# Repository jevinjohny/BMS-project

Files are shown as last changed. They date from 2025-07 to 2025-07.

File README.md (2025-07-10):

# 🔋 Battery Management System for Low Voltage Low Power Domestic Equipment

🎓 **B.Tech Final Year Project**  
🏫 Government Engineering College, Barton Hill  
👤 **Author**: Jevin Johny V  

---

## 📘 Overview

This project presents a compact, stackable **Battery Management System (BMS)** designed for small domestic devices like robotic vacuum cleaners. It incorporates passive cell balancing, safety protections, and real-time SoC estimation.

---

## 🛠️ Tools & Technologies

- **Microcontroller**: Texas Instruments TMS320F28379D  
- **PCB Design**: KiCad (schematic + 2-layer layout + Gerber)  
- **Simulation**: MATLAB Simulink Embedded Coder  
- **Programming**: Embedded C, ADC configuration, interrupt handling  
- **IC Used**: BQ77915 (cell balancing, protection)

---

## 🧑‍💻 My Contributions

- ✅ Complete microcontroller development (ADC, ISR, SoC logic)
- ✅ Designed custom 2-layer PCB using KiCad with Gerber generation
- ✅ Simulated SoC estimation algorithm in MATLAB
- ✅ Tested protection features and built prototype on hardware

---

## 📂 Project Structure

| Folder | Description |
|---|---|
| `kicad` | Schematic, layout, and Gerber files for the PCB |
| `screenshots` | Photos of hardware, layout, schematic, and testing |
| `README.md` | Project summary |
| `LICENSE` | MIT License (recommended for open source use) |

---

## 🖼️ Preview
### 🔌 Schematic
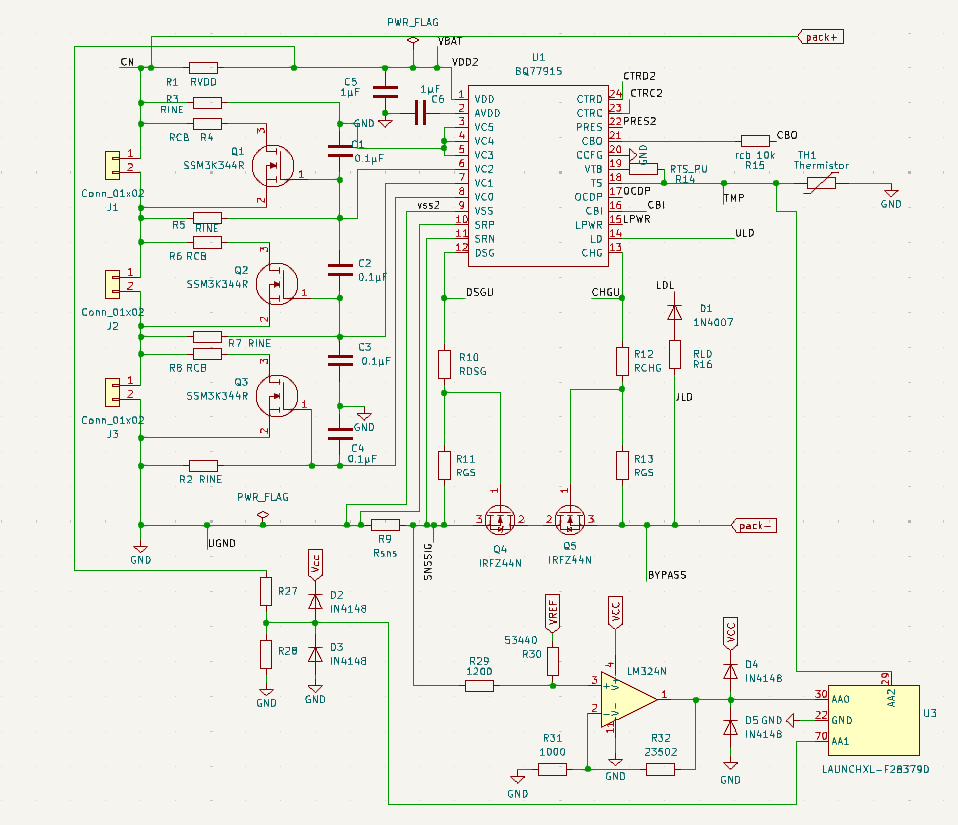
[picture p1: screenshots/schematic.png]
Schematic


### 🔌 PCB Design
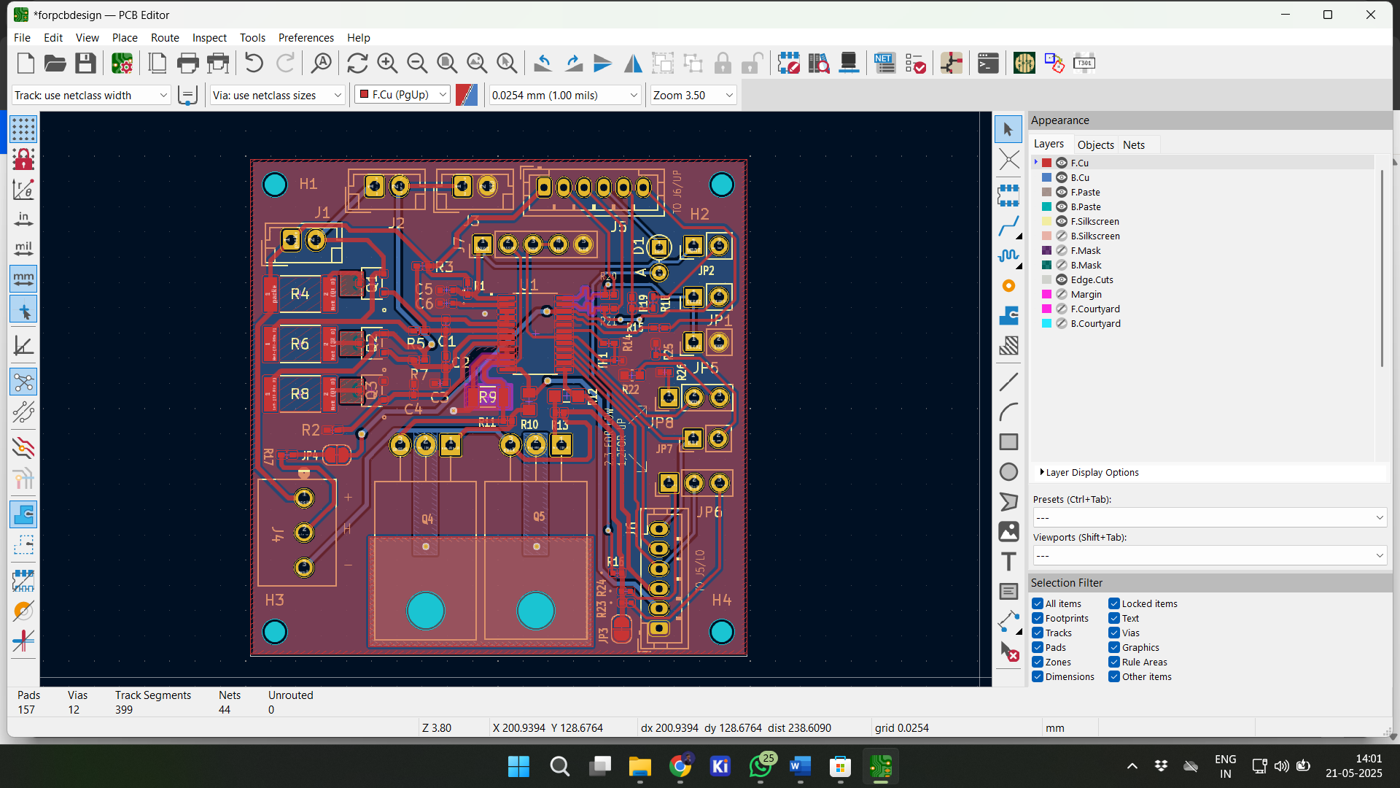
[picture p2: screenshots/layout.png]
Layout


### 🧪 Testing
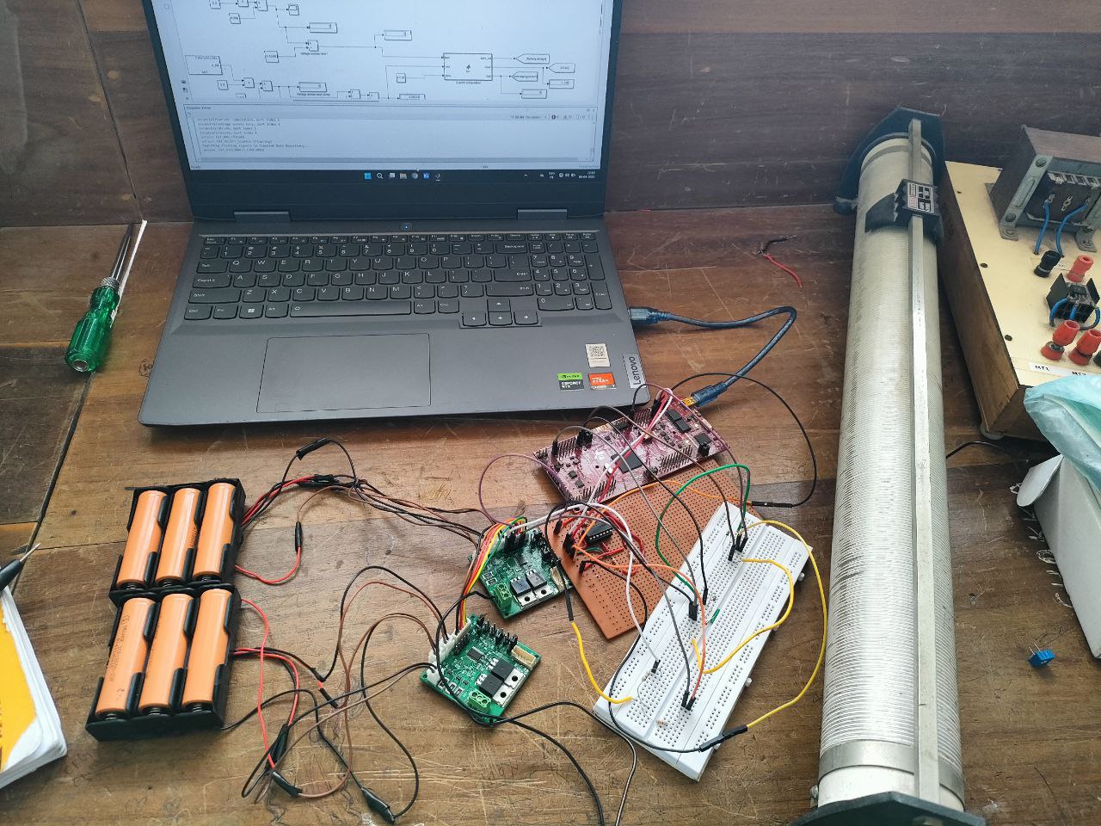
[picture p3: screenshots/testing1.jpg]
Testing


### 📊 MATLAB Simulation
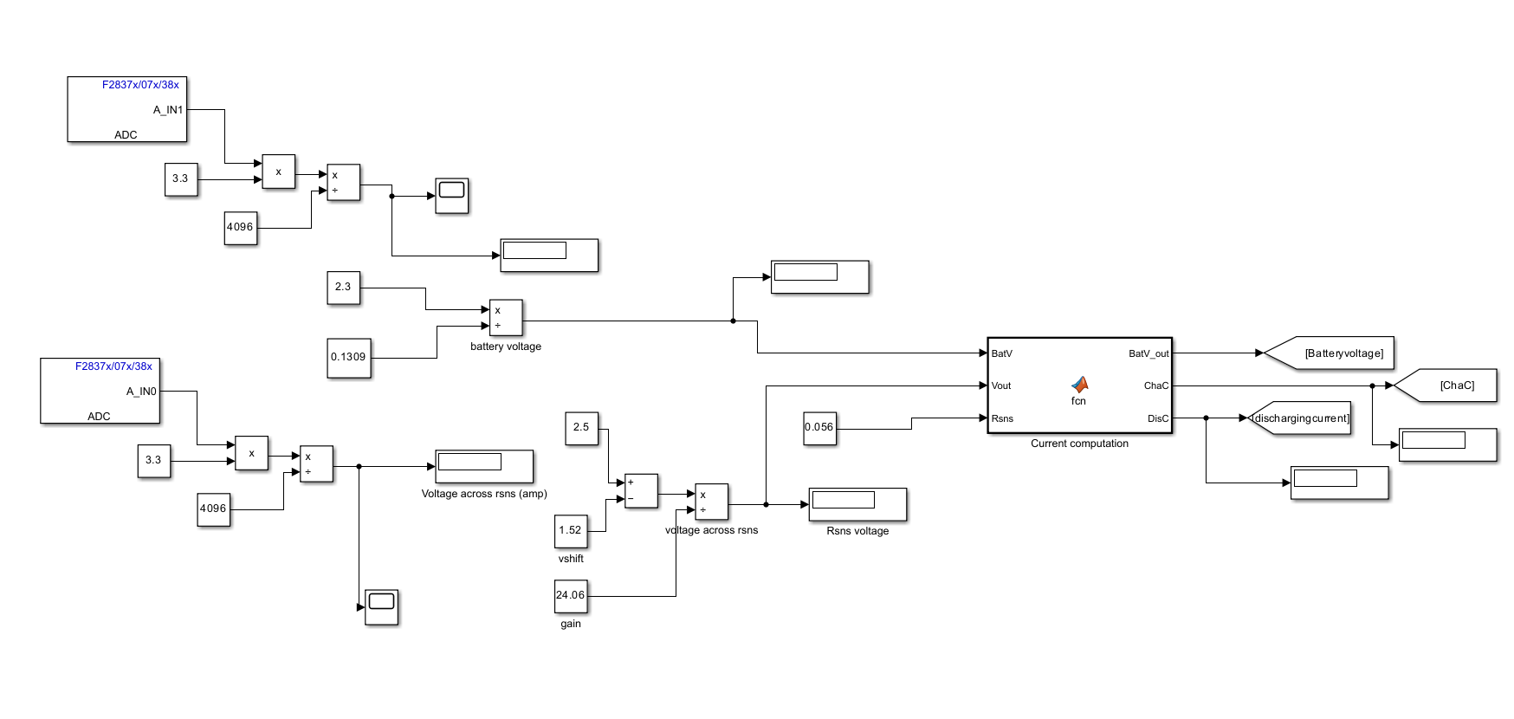
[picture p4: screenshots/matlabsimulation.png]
Simulation


---

## 💡 Features

- Passive balancing with BQ77915 + external FETs
- 6S Li-ion configuration (4.2V max per cell)
- Overvoltage, undervoltage, and thermal protection
- SoC and SoH estimation using modified Coulomb Counting
- Stackable design for scalability

---

## 📬 Contact

I’m actively seeking entry-level opportunities in **Embedded Systems**, **PCB Design**, or **Electronics Engineering**.  
Let’s connect on [LinkedIn](https://www.linkedin.com/in/jevinjohny) (replace with your link).

---

## 📄 License

This project is open-sourced under the MIT License – feel free to explore, adapt, or build upon it.

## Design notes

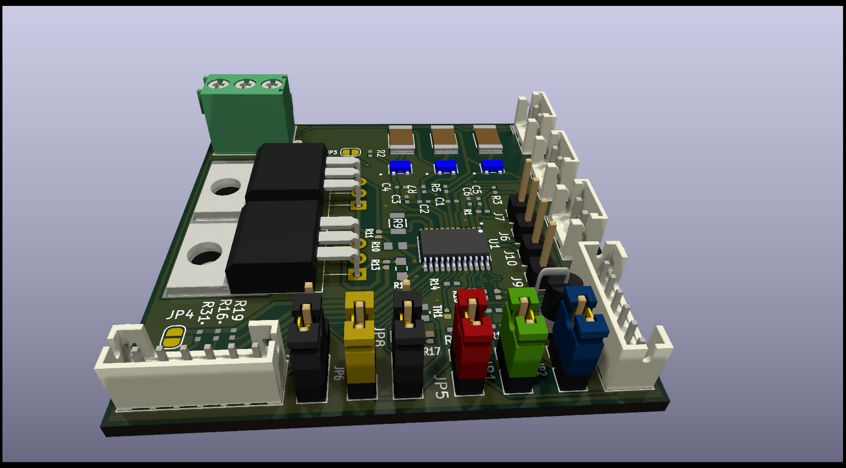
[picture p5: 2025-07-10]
screenshots/3d.png

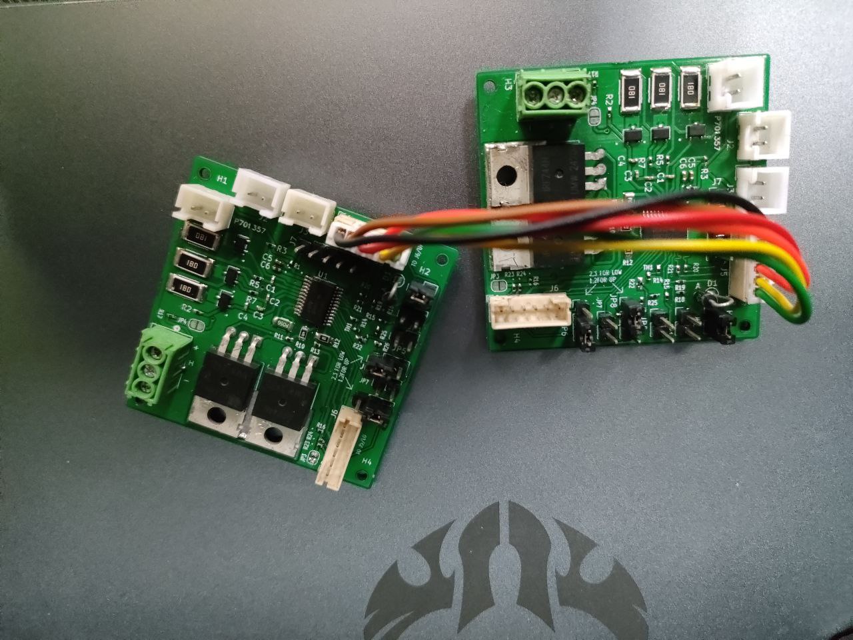
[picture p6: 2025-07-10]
screenshots/pcb.jpg

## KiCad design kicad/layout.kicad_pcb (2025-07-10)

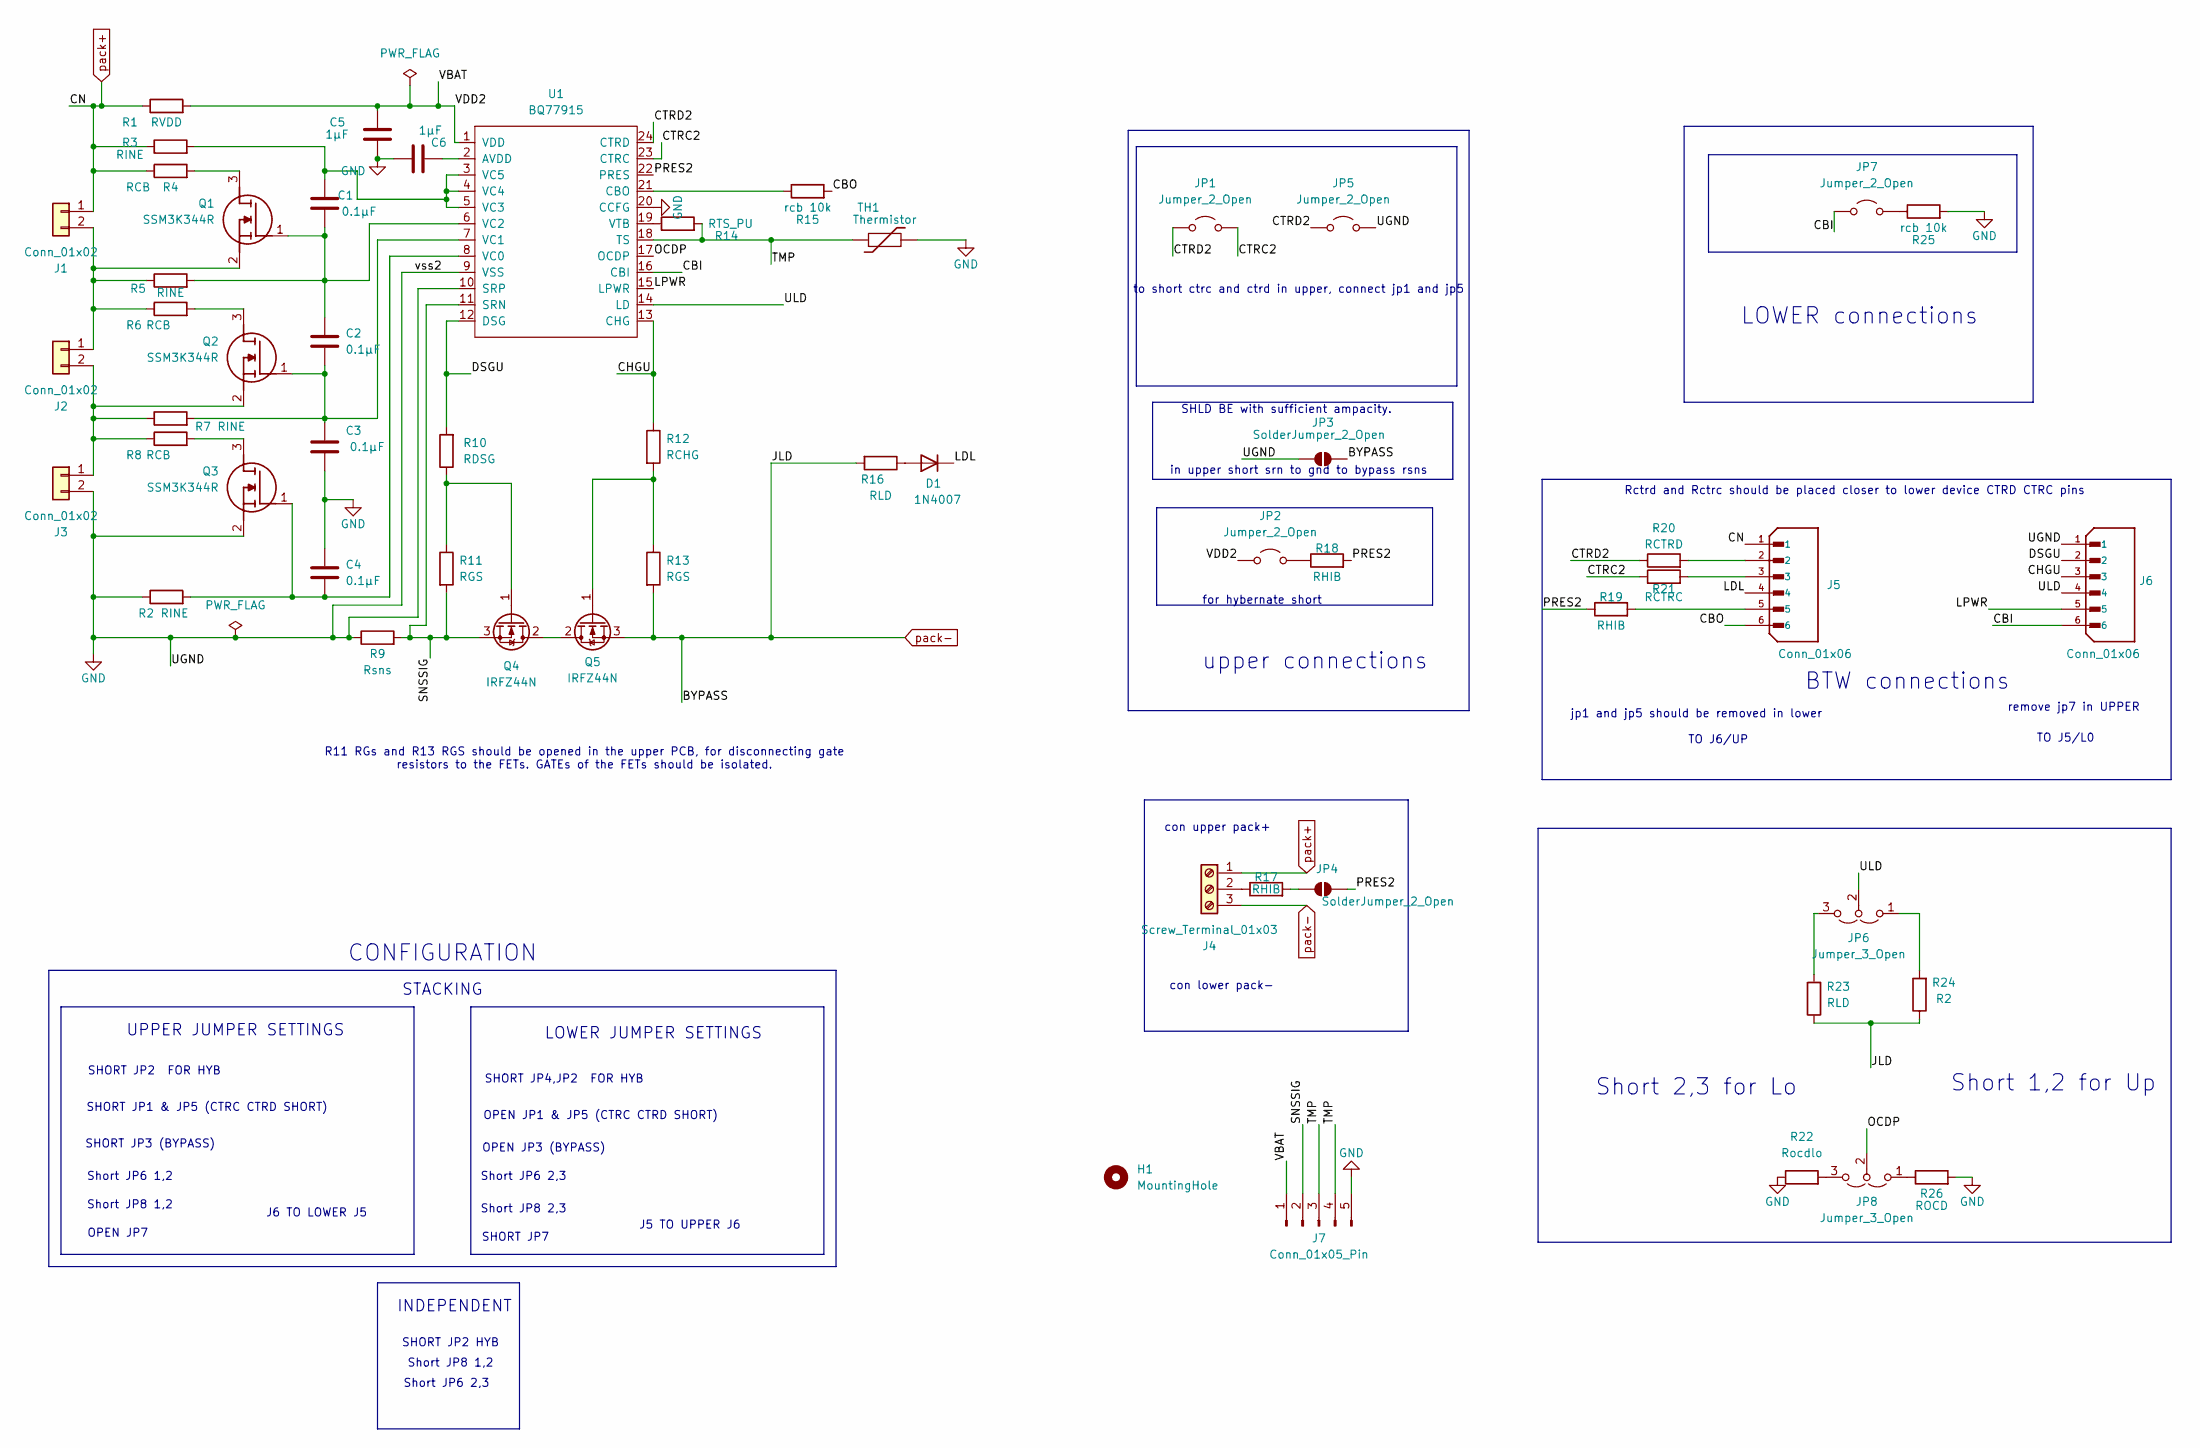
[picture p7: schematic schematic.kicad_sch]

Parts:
C1, C2, C3, C4: 0.1µF; CAP_CL05_SAM; Manufacturer_Part_Number CL05B104KP5NNNC
C5, C6: 1µF; CAP_1005_TDK; Manufacturer_Part_Number GRM033R60J105MEA2D
D1: 1N4007; D_DO-34_SOD68_P2.54mm_Vertical_AnodeUp; Manufacturer_Part_Number 1N4007
H1: MountingHole; MountingHole_2.1mm
J1, J2, J3: Conn_01x02; JST_EH_B2B-EH-A_1x02_P2.50mm_Vertical; Manufacturer_Part_Number B2B-EH-A
J4: Screw_Terminal_01x03
J5, J6: Conn_01x06; JST_PH_B6B-PH-K_1x06_P2.00mm_Vertical; PARTREV 7/4/21
J7: Conn_01x05_Pin; PinHeader_1x05_P2.54mm_Vertical
JP1, JP2, JP5, JP7: Jumper_2_Open; PinHeader_1x02_P2.54mm_Vertical; Manufacturer_Part_Number PH1-02-UA
JP3, JP4: SolderJumper_2_Open; SolderJumper-2_P1.3mm_Open_RoundedPad1.0x1.5mm
JP6, JP8: Jumper_3_Open; PinHeader_1x03_P2.54mm_Vertical; Manufacturer_Part_Number 61300311121
Q1, Q2, Q3: SSM3K344R; SOT-23F_TOS; Manufacturer_Part_Number SSM3K344R
Q4, Q5: IRFZ44N; TO-220-3_Horizontal_TabDown
R1: RVDD; RC0402N_YAG; Manufacturer_Part_Number RC0402JR-071KL
R2, R3, R5, R7: RINE; RC0402N_YAG; Manufacturer_Part_Number RC0402JR-071KL
R4, R6, R8: RCB; RES_RMCF2512_STP; Manufacturer_Part_Number RMCF2512JT18R0
R9: Rsns; RES_1632_SUS; Manufacturer_Part_Number RL1632R-R056-F
R10: RDSG; RC0805N_PAN; Manufacturer_Part_Number ERJ-P06J472V
R11, R13: RGS; RESC1005X40N; Manufacturer_Part_Number CRGCQ0402J1M0
R12: RCHG; RES_ERJP06J102V; Manufacturer_Part_Number ERJ_P06J102V
R14: RTS_PU; RC0402N_YAG; Manufacturer_Part_Number RC0402JR-0710KL
R15, R25: rcb 10k; RC0402N_YAG; Manufacturer_Part_Number RC0402JR-0710KL
R16, R23: RLD; RES_CRGCQ0402J10M_TEC-L; Manufacturer_Part_Number CRGCQ0402J10M
R17, R18, R19: RHIB; RC0402N_YAG; Manufacturer_Part_Number RC0402JR-0710KL
R20: RCTRD; RESC1005X40N; Manufacturer_Part_Number CRGCQ0402J1M0
R21: RCTRC; RESC1005X40N; Manufacturer_Part_Number CRGCQ0402J1M0
R22: Rocdlo; RC0603N_YAG; Manufacturer_Part_Number RC0603FR-07487KL
R24: R2; RES_CRGCQ0402J10M_TEC-L; Manufacturer_Part_Number CRGCQ0402J10M
R26: ROCD; RESC1005X35N; Manufacturer_Part_Number CRCW040210M0FKEDC
TH1: Thermistor; THERM_NTCG103JF103FT1; Manufacturer_Part_Number NTCG103JF103FT1
U1: BQ77915; SOP65P640X120-24N

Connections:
/CBI: J6.6, JP7.1 (A), U1.16 (CBI)
/CBO: J5.6, R15.2
/CHGU: J6.3, R12.1, U1.13 (CHG)
/CTRC2: JP1.2 (B), R21.1, U1.23 (CTRC)
/CTRD2: JP1.1 (A), JP5.1 (A), R20.1, U1.24 (CTRD)
/DSGU: J6.2, R10.2, U1.12 (DSG)
/LDL: D1.1 (K), J5.4
/LPWR: J6.5, U1.15 (LPWR)
/OCDP: JP8.2 (C), U1.17 (OCDP)
/PRES2: JP4.2 (B), R18.2, R19.1, U1.22 (PRES)
/SNSSIG: J7.2, Q4.3 (S), R9.2, R11.2, U1.11 (SRN)
/TMP: J7.3, J7.4, R14.2, TH1.1, U1.18 (TS)
/ULD: J6.4, JP6.2 (C), U1.14 (LD)
/VBAT: C5.1, J7.1, JP2.1 (A), R1.2, U1.1 (VDD)
GND: C3.2, C4.1, C5.2, C6.2, J3.2, J6.1, J7.5, JP3.1 (A), JP5.2 (B), Q3.2 (S), R2.1, R9.1, R22.1, R25.2, R26.2, TH1.2, U1.9 (VSS), U1.10 (SRP), U1.20 (CCFG)
unnamed: D1.2 (A), R16.1
unnamed: J1.2, J2.1, Q1.2 (S), R5.1, R6.1
unnamed: J2.2, J3.1, Q2.2 (S), R7.1, R8.1
unnamed: J4.2, R17.1
unnamed: J5.2, R20.2
unnamed: J5.3, R21.2
unnamed: J5.5, R19.2
unnamed: JP2.2 (B), R18.1
unnamed: JP4.1 (A), R17.2
unnamed: JP6.1 (A), R24.2
unnamed: JP6.3 (B), R23.2
unnamed: JP7.2 (B), R25.1
unnamed: JP8.1 (A), R26.1
unnamed: JP8.3 (B), R22.2
unnamed: Q1.3 (D), R4.2
unnamed: C1.2, C2.1, Q1.1 (G), R5.2, U1.6 (VC2)
unnamed: Q2.3 (D), R6.2
unnamed: C2.2, C3.1, Q2.1 (G), R7.2, U1.7 (VC1)
unnamed: Q3.3 (D), R8.2
unnamed: C4.2, Q3.1 (G), R2.2, U1.8 (VC0)
unnamed: Q4.2 (D), Q5.2 (D)
unnamed: Q4.1 (G), R10.1, R11.1
unnamed: Q5.1 (G), R12.2, R13.1
unnamed: C6.1, U1.2 (AVDD)
unnamed: R15.1, U1.21 (CBO)
unnamed: C1.1, R3.2, U1.3 (VC5), U1.4 (VC4), U1.5 (VC3)
unnamed: R14.1, U1.19 (VTB)
pack+: J1.1, J4.1, J5.1, R1.1, R3.1, R4.1
pack-: J4.3, JP3.2 (B), Q5.3 (S), R13.2, R16.2, R23.1, R24.1

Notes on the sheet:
Short JP8 2,3
Short 2,3 for Lo
R11 RGs and R13 RGS should be opened in the upper PCB, for disconnecting gate resistors to the FETs. GATEs of the FETs should be isolated.
OPEN JP7
Short JP6 1,2
con lower pack-
OPEN JP1 & JP5 (CTRC CTRD SHORT)
LOWER connections
in upper short srn to gnd to bypass rsns
SHLD BE with sufficient ampacity.
SHORT JP2 HYB
STACKING
SHORT JP3 (BYPASS)
INDEPENDENT
con upper pack+
Short 1,2 for Up
J6 TO LOWER J5
SHORT JP2 FOR HYB
Short JP6 2,3
SHORT JP1 & JP5 (CTRC CTRD SHORT)
upper connections
SHORT JP4,JP2 FOR HYB
for hybernate short
LOWER JUMPER SETTINGS
Short JP8 1,2
to short ctrc and ctrd in upper, connect jp1 and jp5
OPEN JP3 (BYPASS)
TO J5/L0
SHORT JP7
BTW connections
jp1 and jp5 should be removed in lower
UPPER JUMPER SETTINGS
TO J6/UP
J5 TO UPPER J6
CONFIGURATION
remove jp7 in UPPER
Rctrd and Rctrc should be placed closer to lower device CTRD CTRC pins

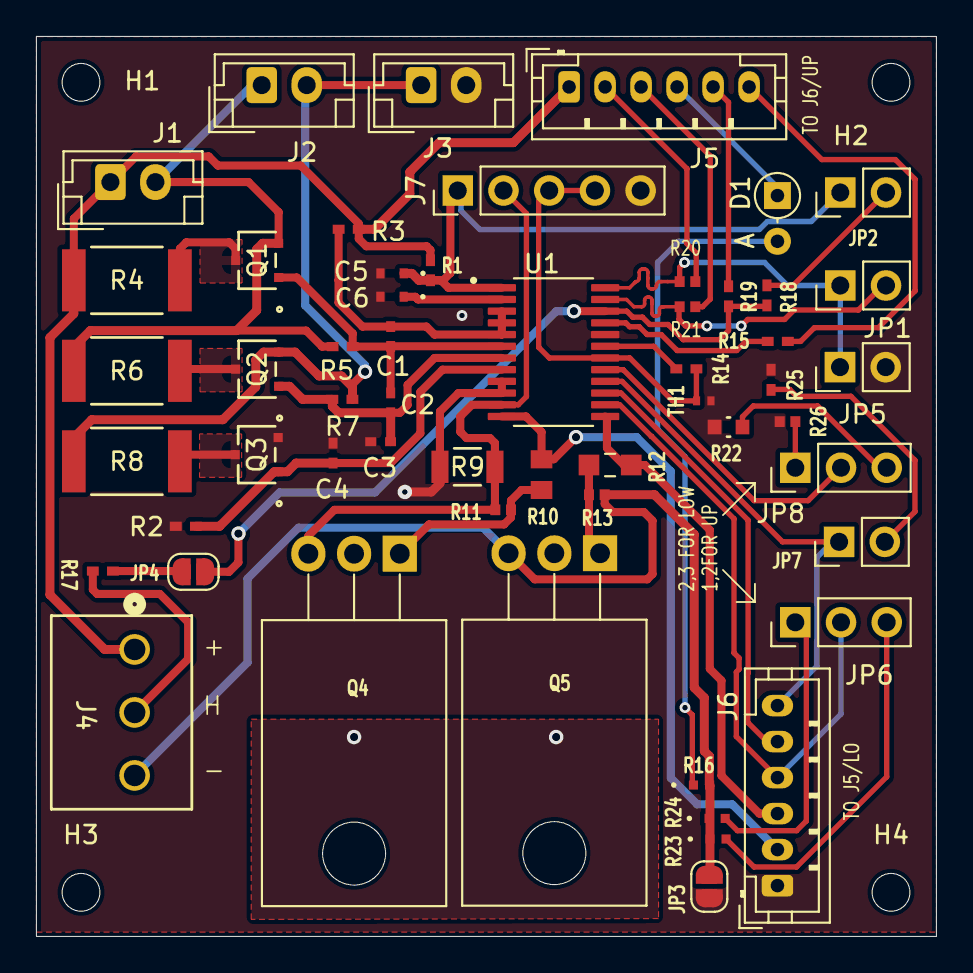
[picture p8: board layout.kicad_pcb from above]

Board: 2 copper layers, 50.0 x 50.0 mm, 59 parts (0 on the bottom side), 44 nets.

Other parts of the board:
H2, H3, H4: MountingHole; MountingHole_2.1mm

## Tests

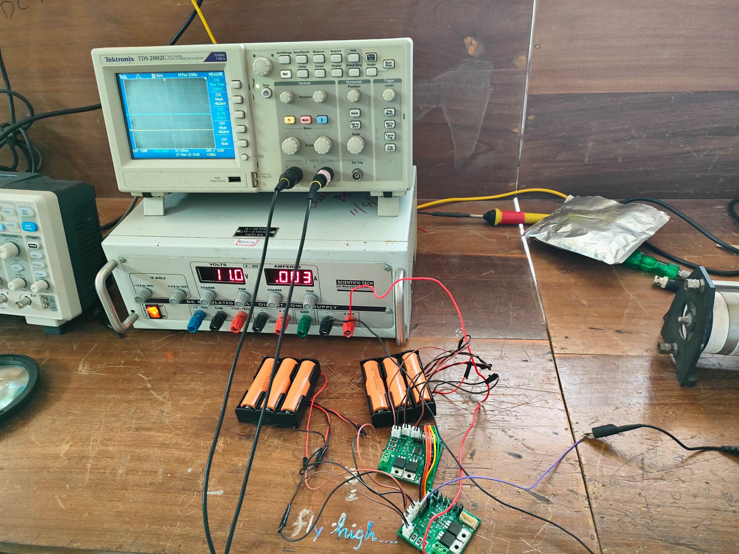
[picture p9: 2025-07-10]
screenshots/testing2.jpg
